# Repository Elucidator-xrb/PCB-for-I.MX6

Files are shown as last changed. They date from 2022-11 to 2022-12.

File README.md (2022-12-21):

## 注意事项

改前记得pull，改后记得及时commit + push，一个master分支到底了。AD09本身似乎不支持VCS，要是冲突了感觉稍有些难整。

改用了AD2022，不过协同使用似乎还是弄不起来；尝试了Windows局域网共享文件也不work，就先串行设计吧

## 电源流向梳理

#### 外界电源

外界电源接口：**J5**，**J6**

关于那个奇怪的**+12V** ，其实是一个测试点，可以制板后万用表加上电压测试

产出电源12VIN

#### 12VIN

12VIN -> 5V_core

12VIN -> 5V_EX

#### 5V_core

5V_core -> GEN_3V3 （通过U15 - LX引脚）

=> Connector: U10 - S153~S158

去耦电容电路： C137 C138 C139

#### 5V_EX

=> HDMI: U13-5V_SUPPLY

=> LVDS: 仅有的J11的供电

=> USB HUB: U9 - VIN  U14 - VIN

=> POWER LIGHT: 其一红灯

#### GEN_3V3

=> UART：U1 - VCC   J16, J17接口的电源

=> HDMI:  U13 - LV_SUPPLY ...	J13

=> USB HUB

=> RTC: U12 - VBAT, VDD

=> KEY: U2 - VCC, nRST

=> USER LIGHT 

=> BUTTON

GEN_3V3 -> RGMII_3V3 （转换电路，附带去耦电容，Ethernet处）

GEN_3V3 -> VCC_1V2 （Ethernet处）

#### VCC_1V2

VCC_1V2 -> RGMII_1V2（转换电路，附带去耦电容）

VCC_1V2 去耦电容电路（Ethernet处）

#### 3P3V - （核心板反向输出）

=> Connector: U10 - S149~S152 从核心板中输出，**用于核心板对外传递信息**

=> PWR_IN: U15 - **EN** 使能端

=> POWER LIGHT: 两外两个绿灯

=> BOOT 拨码开关

#### 2P5V - （核心板反向输出）

=> Connector: U10 - P150, P149 从核心板中输出，**用于核心板对外传递信息**

=> Ethernet: U8 - **nINT**, **nRESET**, **MDIO**, **DVDDH**（共3个管脚）

2P5V 去耦电容电路（Ethernet处）

#### RGMII类

RGMII_3V3

RGMII_1V2

用于Ethernet

#### USB类 - （通过USB口外界来嘛）	

USB_OTG_VBUS

USB_H1_VBUS

## 工作日志

初始化了大致布局

#### 11/23

rain

button的布局和部分连线

#### 11/24 

xrb

根据引脚宽度，线宽一般设为12mil，过孔12/24mil；

目前操作中感觉，把当前想布局布线的模块中相关元件（各种电阻电容）的连线显示，其他连线隐藏，会方便清爽些（快捷键'N'）

GND、电源的焊盘可以先不连，最后一律打过孔到GND/PWR层（这也是4层PCB比2层PCB简单的地方）

自动布线尚未尝试，感觉也挺棘手，电阻电容都还没布局

进行了HDMI模块相关小元件布局和布线，未完成，且有些疑问

#### 11/25

wz

布局+布线左下方usb相关电容电阻

#### 11/26

rain

把右侧的button和connector的电阻进行了布局和接口间的连线。

疑问：所谓的电源去耦电容的排布，即什么是放在使用的旁边

#### 11/27

xrb

调整了按键KEY15 - R15和Connector的连线方式，因为其挡到了Ethernet - U8 的布线

修改了几乎所有KEY上方的布线，不知道改的行不行，使其不至于横跨半块板而影响U8与Connector附近过孔的设置

**发觉原理图好些标识倒过来了**，很奇怪；同时发现**Ethernet中R120电阻标成了R125（？！）**，好在R125是我们没选的CAN模块上的电阻，所以无所谓了不改了，**以后R120就是原理图的R125**

排列归类了一下Ethernet有关电源的部分，但不是很清楚流向以及布局

LVDS就接了一根，还不能最终确定布线

#### 11/28

wz

调整rtc及rtc电池位置，调整数码管及其控制芯片 （U2）位置，连接uart部分，连接右侧usb-otg，调整部分过孔尺寸，优化connector-ethernet 及usb-otg布线。

主要剩余lvds及power。

#### 11/29

xrb

连接JTAG部分；管理层设置显示了全部layer，导致一些多余层显示出来（麻烦不想删了），若想关掉可以隐藏Mechanical21、18、23；把Connector的位置给锁了，终于不会误移动，元件也不会被覆盖了

尝试打过孔到GND，发现这个也挺棘手，不会；为此增加过孔的几种类型（1:2 1:3 2:4 3:4），但不知是不是这么用的；然后发现快捷键产生的default过孔变成bind3:4了，干脆全删了；

连接key数码管部分; 连接了USB漏下的几个电阻；SW1是系统启动的拨码开关，不应该放在Connector能被核心板覆盖的地方，所以移动了它的位置并连了线

梳理了下电源产生和流向的问题，已得老师回复：关于去耦电容，应该布在**芯片电源输入引脚**附近；Connector页的BH是整块PCB板的固定孔；

还是剩 LVDS-差分线、 电源一大块

zyc

记录一些问题

NETC27_2应该接地，但由于原理图绘制时的问题导致无法连接

RB056L-40TE25（**D9、D10**）二极管不会标注引脚，而且存在正负极差异，该处可能出现问题

U4芯片对应的是5V_core而非5V_ex

把三个电源的部分大致完成（5V只做了一半），等待后序的布线优化再放置

#### 11/30

xrb

缩小了板子下边界，移动了8个按键位置，并再次调整了其布线，仍然有些难看；**Connector左侧的电阻其自带丝印其实早就没咧，仅有的是时候加的，好像不能和焊盘重叠；丝印的摆放似乎也需要注意**

重新排布了U2、U12部分的电路，为了给电源腾空间，感觉还是有点挤不好看。

差分线：除了LVDS，网口、等等几乎全是，均需要重画；**等长线要放在发送端**

> 差分线相关操作：快捷键U 

需从原理图将其改成差分线，已修改LVDS处（对应Connector对应处似乎不用改，只加了一处，总之**validate会报错但是导入又成功**）

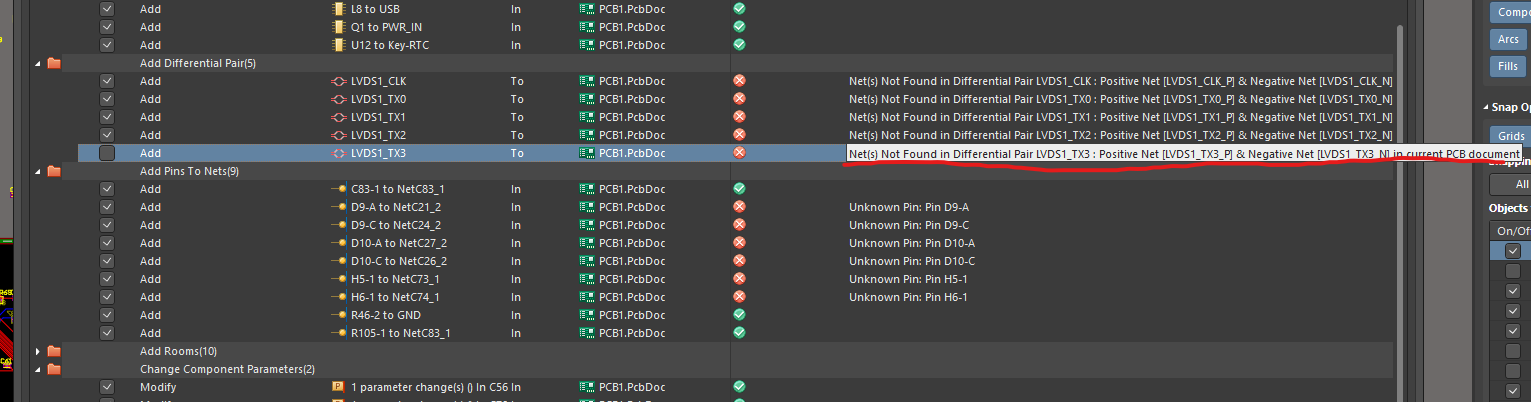
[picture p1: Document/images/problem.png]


起初导入后也画不了差分对，后来发现是规则设置问题

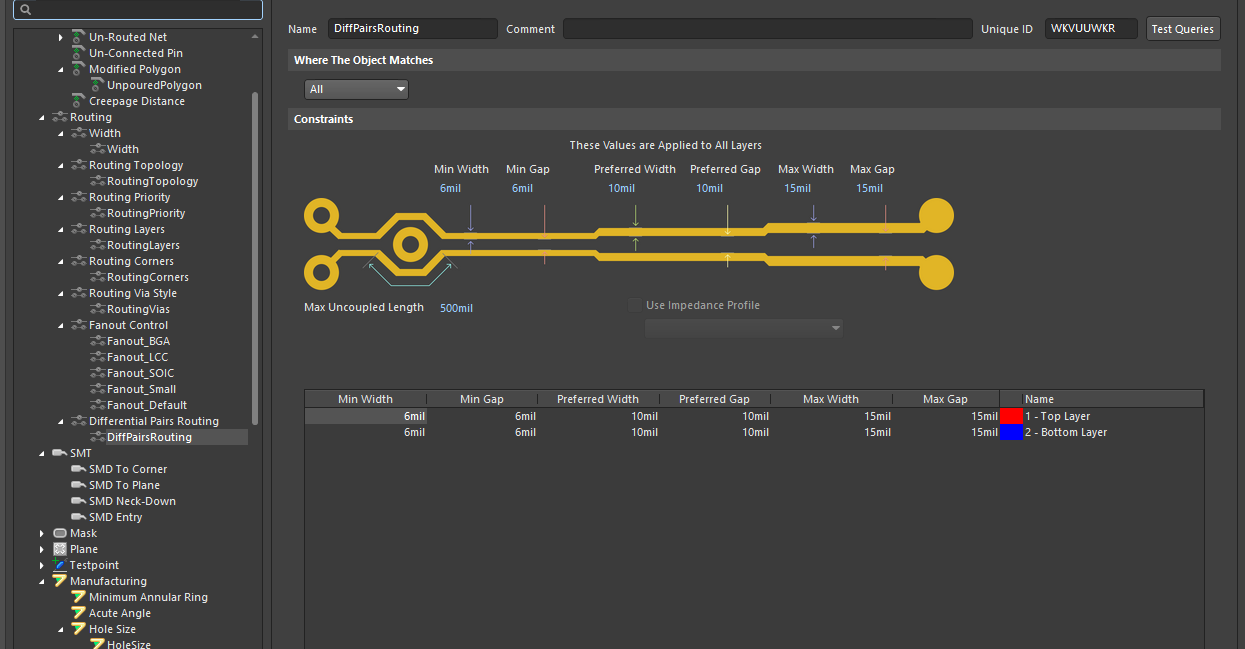
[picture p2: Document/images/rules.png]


画时用这两个分别布线和调等长，可以通过快捷键U调出相关选项；**阻抗匹配的问题**还不知道怎么设置欸

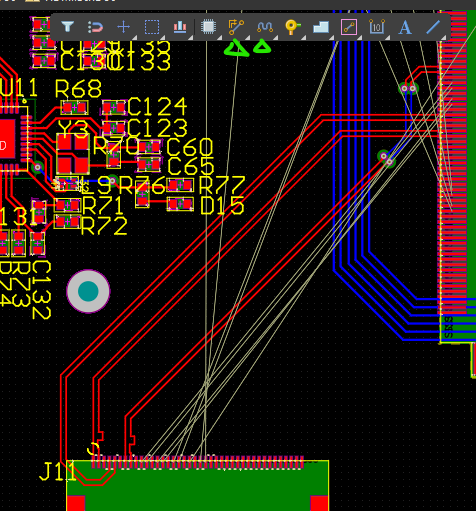
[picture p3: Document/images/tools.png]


只是做了个添加尝试，大致可行，之后需改原理图+调布局了

#### 12/1

wz

移动了ethernet uart usb-otg的位置到板卡下方。

连接了lvds，ethernet，uart，并完成了lvds和ethernet的等长。

但是等长似乎在保存之后会混乱，需要重新做一次等长才有效果，不确定是否正确。

调整了ethernet的pcb库，似乎之前的是反的。

usb这边暂时没有连接，不确定相关元件与等长配合的连接方式。

#### 12/2

zyc

#### 12/4

xrb

重新布置了hdmi相关的连线，用了ad提供的差分线工具，由于线顺所以较为顺利；

原理图上添加了除USB外的差分线并导入了pcb，修补了wz差分线的奇怪残缺，**似乎倾斜的情况没法用ad的工具了，且重新显示的蛇形线很方**，可能得手动画；

连了一些边角的net；把I2C剩余连完，将usb电源部分移入相关区域；

添加了GND02层的net；**PWR03层电源区域的划分需要考虑起来**，应根据表层电源的分布，在PWR03这个负片上作分割，并添加到不同的电源net上

#### 12/5 & 12/6

wz

连接了usb-otg 以及usb-host。靠上的usb-host没有做等长，不确定是否需要做。

明天晚上再补充一下

#### 12/9

zyc

#### 12/10 & 12/11

xrb

原理图中PWR_IN中D9和D10所用二极管应为肖特基二极管，画得有误导性导致该部分PCB导入失败；重新替换并导入PCB；

添加USB部分原理图上的差分对（否则每次update都会有remove已有差分对的选项，得一个个点掉很烦），并导入PCB（之后还能时刻提醒这是差分对）；

把地层复原了一下；重新布置了button的线，并重新排布了几块电源产生的电路；

又发觉**Ethernet处一溜电源的去耦电容封装选错（类似C107这种本应SC0805封装设成了SC0603）**，可能当时复制后忘改了qwq，修改并重新导入；Ethernet页所有的0805封装全部添加成了0603，**仅检查改正了该页，其他页尚待检查**；

> 困惑：为何新update的元件（左侧）颜色和原先的元件（右侧）不同？应该不是封装的原因，也有见过先前就是0805的封装但底色就是绿色而非草绿

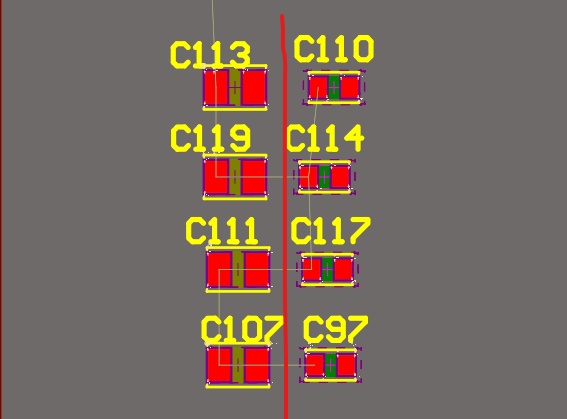
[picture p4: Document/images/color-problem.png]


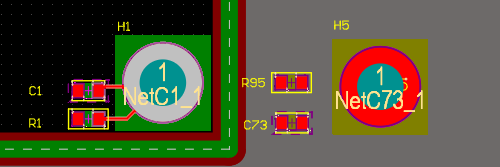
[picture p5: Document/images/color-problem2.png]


Ethernet有一个GND脚报错的原因是**重叠了好些断线**，清理了；

Connector原理图有个5V_core写成了VCC，修正了；

关于H5和H6的未知Pin问题，删了PCB元件重新导入就行，奇怪

将所有**高36mil，线宽10mil**统一改成了**高20mil，线宽5mil**（操作：选择相似对象），这样丝印的排布会方便些（尽量不要压倒布线，**尤其是差分对**）；

U15处的电源尝试性的铺铜，接了一些地；将去耦电容放到了题目该在的位置（其实都在Ethernet周围）；

--》接下来主要工作便是**连接电源和地**，U3和U4的排布还没怎么看

#### 12/12

wz

完成pwr层分区

#### 12/17

xrb

划分好GEN_3V3的区域，并连线；期间发现U11附近的线太紧没法打孔，所以重新布了一条差分对

划分好VCC_1V2的区域，并连线；

调整了2P5V的区域，并连线；

划分了RGMII_3V3和RGMII_1V2，并连线

调整了5V_EX的区域，并连线；

调整了12VIN，并连线；

顺路连了些GND，未全

#### 12/21

xrb

补全了余下所有的线：

**USB_OTG_VBUS的连法令人糟心**

U8上的两个NC管脚之间没连上，不知要不要连，但也没啥空间了

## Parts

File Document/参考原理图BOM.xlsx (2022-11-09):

Bill Of Materials October 6,2022 1:02:41
Item | Quantity | Reference | Part
1 | 4 | BR1,BR2,BR3,BR4 | CD143A-SR05
2 | 1 | BT1 | CR2032
3 | 16 | C1,C41,C42,C50,C58,C72,C73,C74,C75,C76,C77,C82,C84,C112,C131,C134 | 1000pF 50V
4 | 11 | C2,C3,C4,C5,C6,C7,C8,C9,C29,C31,C86 | 100pF 50V
5 | 61 | C10,C12,C13,C14,C15,C20,C21,C22,C23,C25,C27,C38,C39,C40,C48,C57,C59,C61,C62,C64,C66,C67,C68,C69,C71,C80,C81,C83,C87,C89,C91,C92,C93,C94,C95,C96,C97,C98,C99,C100,C102,C103,C106,C108,C110,C113,C114,C115,C116,C117,C118,C120,C121,C122,C124,C125,C127,C128,C132,C133,C136 | 0.1uF 50V
6 | 1 | C11 | 47uF 16V(RVT1C470M0605)
7 | 2 | C16,C18 | 22uF 25V
8 | 8 | C17,C19,C37,C78,C79,C137,C138,C139 | 22uF 10V
9 | 2 | C24,C26 | 0.47uF 16V
10 | 2 | C28,C30 | 0.01uF 50V
11 | 6 | C32,C123,C126,C129,C130,C135 | 1uF 16V
12 | 2 | C33,C35 | 0.1uF(NC)
13 | 2 | C34,C36 | 2200pF 50V
14 | 13 | C43,C49,C51,C56,C63,C70,C101,C104,C105,C107,C109,C111,C119 | 10uF 16V
15 | 3 | C44,C60,C65 | 33pF 50V
16 | 4 | C46,C47,C54,C55 | 56pF 50V
17 | 2 | C52,C53 | 18pF 50V
18 | 1 | C85 | 560pF 50V
19 | 2 | C88,C90 | 10pF 50V
20 | 1 | DP1 | LEDTube-RED
21 | 10 | D1,D2,D3,D4,D5,D6,D7,D8,D18,D19 | LED_GREEN
22 | 2 | D9,D10 | RB056L-40TE25
23 | 1 | D11 | MMSZ5243BT1G
24 | 1 | D12 | SMF12A
25 | 1 | D13 | SS32
26 | 1 | D14 | MBR0520LT1G(NC)
27 | 2 | D15,D17 | LED_RED
28 | 1 | D16 | BAT54HT1
29 | 1 | F1 | FUSE 3A
30 | 5 | H1,H2,H4,H5,H6 | BH
31 | 1 | J2 | ENT_POWER
32 | 1 | J3 | 5557-4p-4.2x5.5
33 | 1 | J5 | POWER_DC5V
34 | 1 | J6 | CON2
35 | 2 | J7,J9 | DG141R-2.54-2p
36 | 1 | J8 | HR851174C
37 | 1 | J10 | USB_A_Double
38 | 1 | J11 | xf2m-4015-1a
39 | 1 | J12 | A01SB1441B01-457
40 | 1 | J13 | 10029449-001RLF
41 | 1 | J14 | JTAG_W_20pin
42 | 1 | J15 | USB_A
43 | 2 | J16,J17 | A2501WV-4P
44 | 8 | KEY1,KEY2,KEY3,KEY4,KEY5,KEY6,KEY7,KEY8 | SW PUSHBUTTON-SPST-2
45 | 2 | L1,L2 | CLF10040T-100M
46 | 1 | L3 | LQM2HPN2R2MJ0L
47 | 5 | L4,L5,L8,L9,L10 | DLM11SN900HY2L
48 | 3 | L6,L12,L13 | BLM18PG121SN1D
49 | 1 | L7 | 120 ohm/BLM18PG121SN1D
50 | 1 | L11 | SPM4012T-2R2M
51 | 1 | Q1 | MMBT3906LT1G
52 | 1 | Q2 | Si7129DN-T1-GE3
53 | 13 | R1,R47,R64,R92,R95,R96,R97,R98,R99,R100,R106,R126,R127 | 100R 5%
54 | 23 | R2,R3,R6,R7,R8,R9,R12,R13,R14,R15,R18,R19,R20,R23,R24,R76,R93,R94,R105,R120,R121,R124,R129 | 1K 5%
55 | 19 | R4,R5,R10,R11,R16,R17,R21,R22,R26,R27,R32,R34,R55,R88,R89,R90,R91,R103,R123 | 10K 1%
56 | 1 | R25 | 0.1R 1%
57 | 7 | R28,R30,R72,R73,R74,R75,R77 | 100K 1%
58 | 2 | R29,R31 | 84.5K 1%
59 | 2 | R33,R35 | 16K 1%
60 | 3 | R36,R41,R46 | 470K 5%
61 | 2 | R37,R42 | 470K(NC)
62 | 18 | R38,R43,R62,R63,R65,R66,R67,R69,R71,R79,R80,R86,R87,R116,R118,R122,R125,R128 | 0R 5%
63 | 5 | R39,R40,R44,R45,R101 | NC
64 | 4 | R48,R53,R54,R61 | 30R 5%
65 | 2 | R49,R50 | 360K 1%
66 | 2 | R52,R56 | 120R 5%
67 | 1 | R57 | 2M 1%
68 | 1 | R58 | 12.1K 1%
69 | 4 | R59,R60,R82,R83 | 4.7K 1%
70 | 1 | R68 | 12K 1%
71 | 1 | R70 | 1M 5%
72 | 3 | R78,R85,R112 | 47K 5%
73 | 1 | R81 | 15K 5%
74 | 1 | R84 | 27K 5%
75 | 1 | R102 | 75K 1%
76 | 1 | R104 | 24K 1%
77 | 1 | R107 | 49.9K 1%
78 | 1 | R108 | 33K 1%
79 | 8 | R109,R110,R111,R113,R114,R115,R117,R119 | 270R 5%
80 | 1 | SW1 | DHN-02
81 | 1 | TP1 | TEST POINT
82 | 1 | U1 | SP3232EEY
83 | 1 | U2 | ZLG7290
84 | 2 | U3,U4 | R1270S001A-E2-KE
85 | 2 | U5,U7 | TJA1040T
86 | 1 | U6 | TPS62240DDCR
87 | 1 | U8 | KSZ9031RNXCC
88 | 2 | U9,U14 | LM3526MX-H
89 | 1 | U10 | MXM314
90 | 1 | U11 | USB2514B-AEZC
91 | 1 | U12 | ISL1208
92 | 1 | U13 | CM2020
93 | 1 | U15 | RT8070ZSP
94 | 2 | U16,U17 | NLSV1T34DFT2G
95 | 1 | Y1 | 4MHZ
96 | 1 | Y2 | 25MHz
97 | 1 | Y3 | 24MHz
98 | 1 | Y4 | 32.768KHZ

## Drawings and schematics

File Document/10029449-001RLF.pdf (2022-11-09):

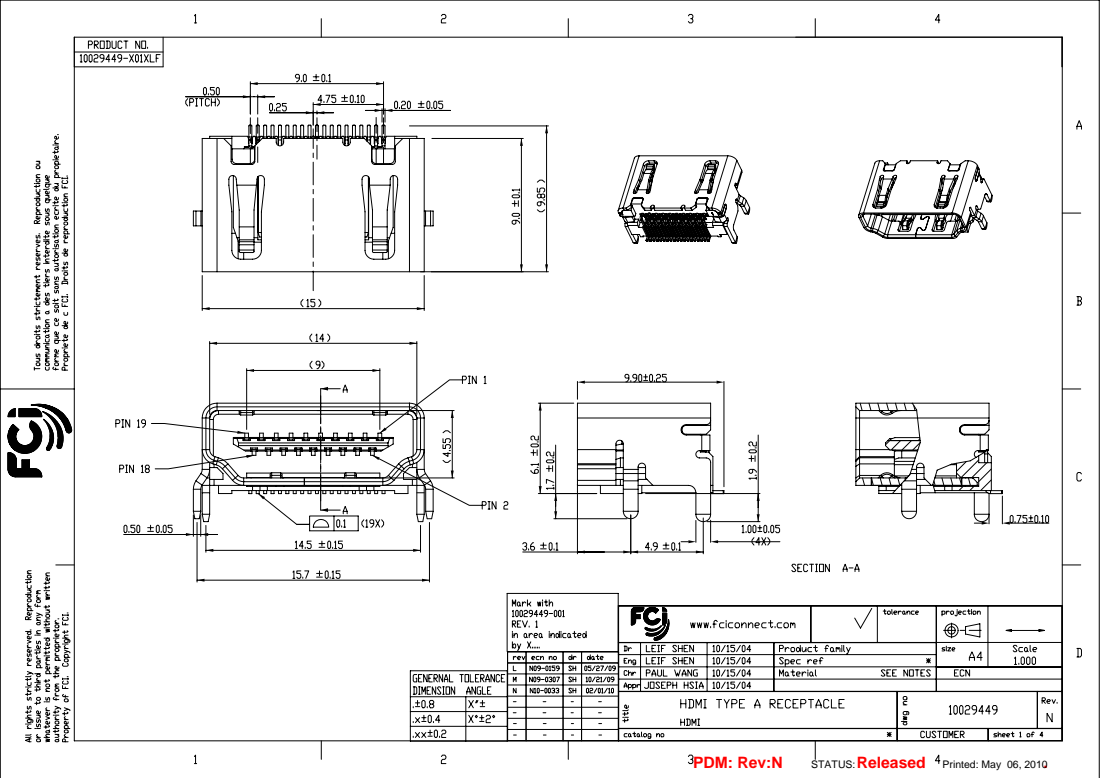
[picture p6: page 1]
PDM: Rev:N; Released; . STATUS:; Printed: May 06, 2010

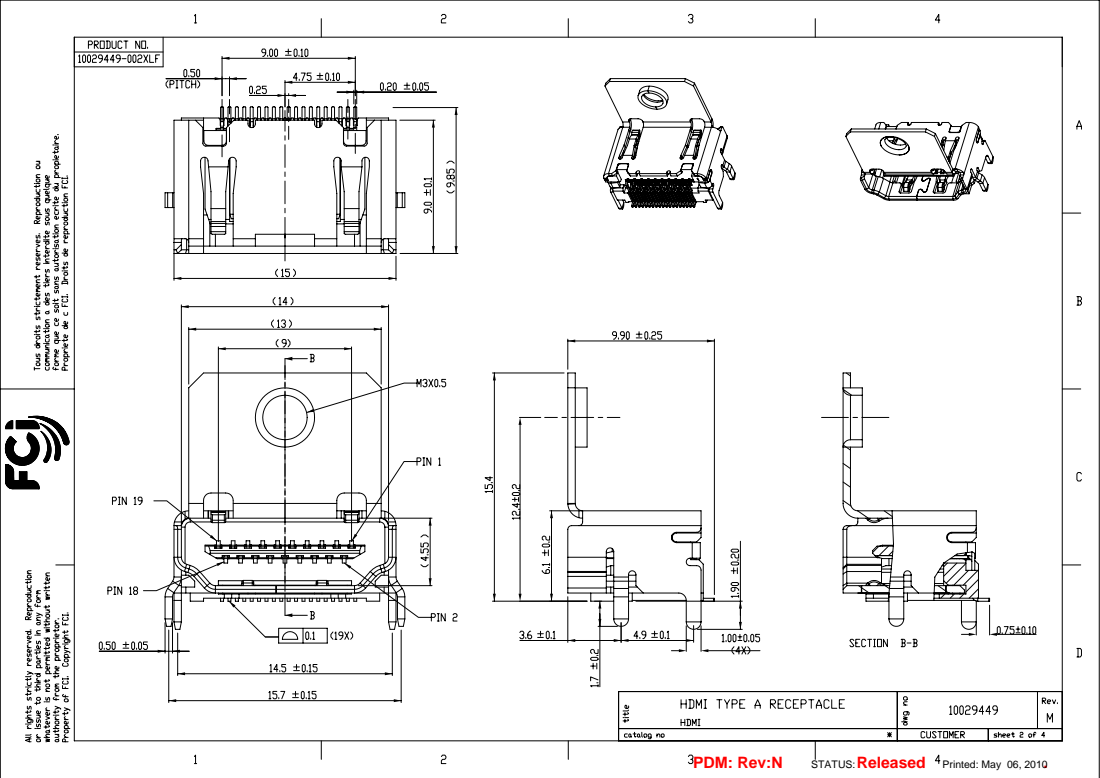
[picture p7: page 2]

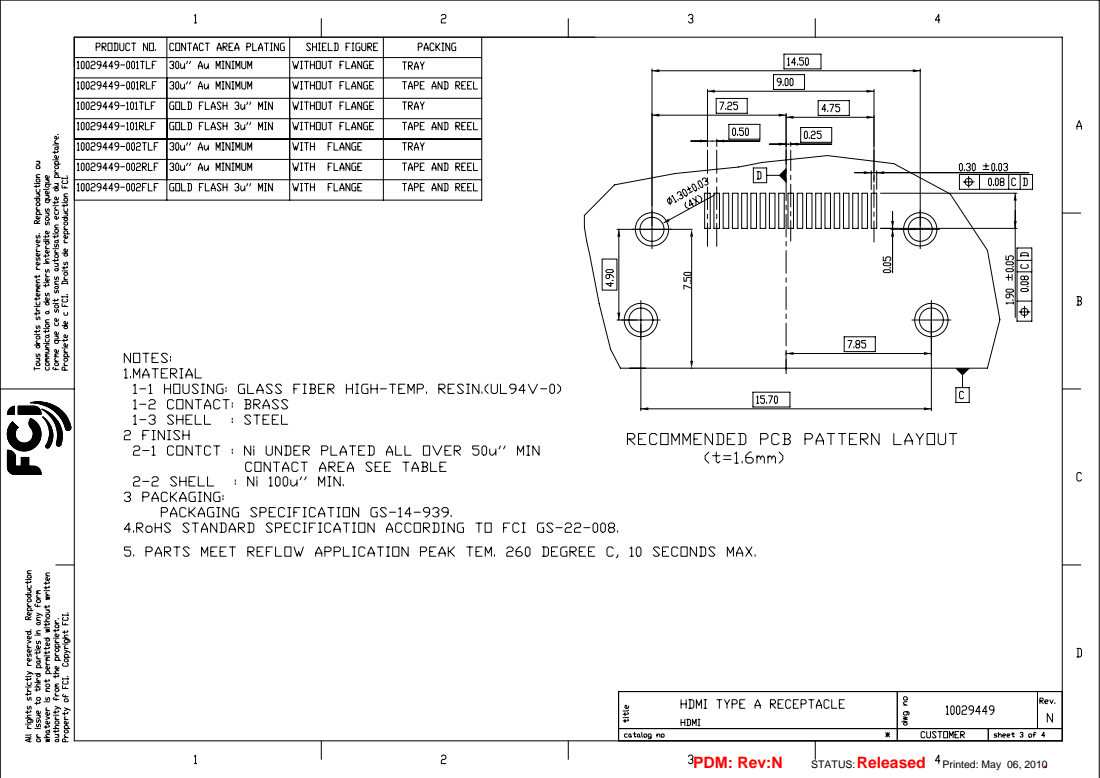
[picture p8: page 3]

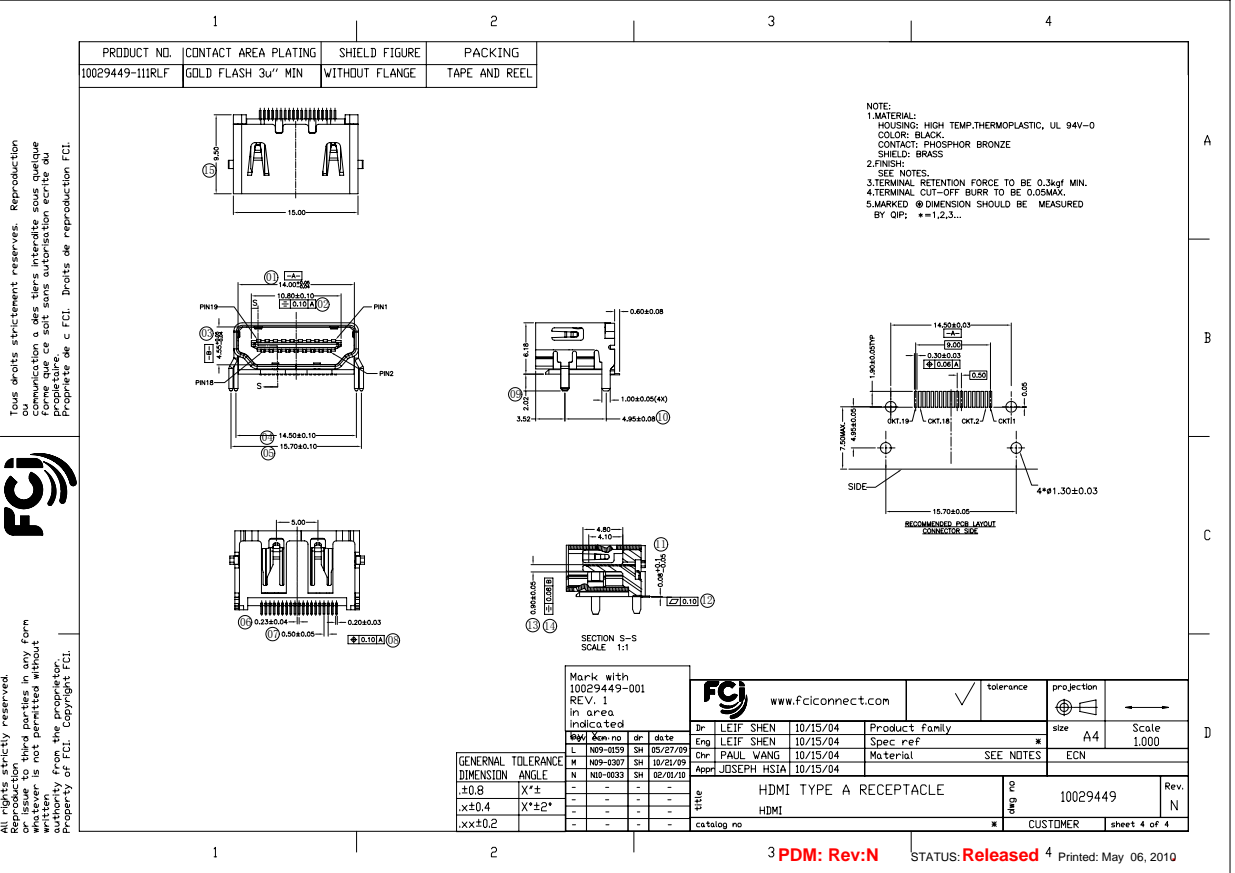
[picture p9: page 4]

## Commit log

2022-11-09 init files
    [Button.SchDoc, Connector.SchDoc, Ethernet.SchDoc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]
2022-11-09 clear port direction error (may not necessary)
    [Button.SchDoc, Connector.SchDoc]
2022-11-09 exchange one invalid footprint (U8 KSZ9031RNXCC). it's weird, i've changed before)
    [Ethernet.SchDoc]
2022-11-09 init pcb file and import changes from project
    [PCB_Project.PrjPCB]
2022-11-09 init document
    [分工.xlsx, 参考原理图BOM.xlsx]
2022-11-22 init PCB layout for component
    [PCB_Project.PrjPCB]
2022-11-22 set pull back distance for GND02 and PWR03
2022-11-23 enlarge the board, refract some layout. do not known how to place LVDS J11
2022-11-24 连接了button的小电路
2022-11-25 basically finished wiring of HDMI
2022-11-25 add: USB
    [PCB_Project.PrjPCB, USB.SchDoc]
2022-11-26 connector and button
2022-11-27 basically finished layout and wiring of Ethernet, little refraction of global layout and change wiring of keys
2022-11-29 finished today, switch~
2022-11-29 changes that i didn't know
    [PCB_Project.PrjPCB]
2022-11-30 before intention to place diff pairs
    [LVDS.SchDoc]
2022-11-30 before re-update SchDoc for diff pairs
    [LVDS.SchDoc]
2022-12-01 finished 12/1: diff pairs is troublesome and the PCB need refact!
    [Connector.SchDoc, LVDS.SchDoc]
2022-12-01 add: LVDS
    [LVDS.SchDoc]
2022-12-01 移动ethernet和串口到下侧 移动usb-otg到板子下侧，但没连接差分线组
    [Ethernet.SchDoc, MY-I.MX6-PCB_Library.PcbLib]
2022-12-01 修改readme
    [Ethernet.SchDoc, LVDS.SchDoc]
2022-12-04 redraw HDMI with diff pair, add diff pair to most schlib except USB
    [Connector.SchDoc, Ethernet.SchDoc, HDMI.SchDoc]
2022-12-04 repair break wire of ethernet diff pairs
2022-12-05 wz: update usb
    [USB.SchDoc]
2022-12-10 一线导线的添加，对于地层的处理
2022-12-10 把底层复原了一下
2022-12-10 fix D9 and D10: change to Schottky one
    [Connector.SchDoc, PWR_IN.SchDoc]
2022-12-11 before reupdate
    [USB.SchDoc]
2022-12-11 finish today 12/11
    [Connector.SchDoc, Ethernet.SchDoc]
2022-12-11 ?? unknown save changes
    [PCB_Project.PrjPCB]
2022-12-12 完成 usb连线及等长
2022-12-12 完成 电源平面分区
2022-12-14 GND的部分连接
2022-12-17 PWR: RGMII_xxx 5V_EX 12VIN part of GND
2022-12-18 add some GND wire
2022-12-21 change the footprint of HR911130C_0: switch 5-6-7 for conveniench of diff pair connection
    [Ethernet.SchDoc, MY-I.MX6-PCB_Library.PcbLib]
